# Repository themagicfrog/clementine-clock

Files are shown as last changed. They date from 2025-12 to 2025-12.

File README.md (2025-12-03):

# clementine clock

this is an orange/mandarin-themed clock to set timers & alarms for my room. I decided to make a clock because I usually don't have access
to my phone when I go to sleep at school, and I needed an easy way to know the time and to wake up at the right time. I chose a clementine
theme because I like oranges.

on the main PCB board, there is a 4-digit 7-segment LCD display (showing the time), a small button, and a speaker. there is also wires on the
main PCB board connecting a rotary encoder (adjusting the time) on the top of the orange, a 3 AA battery case, and a big button (snooze & stop) at the
"stem" of the clementine. the case is a 3D-printed cylindrical clementine case.

3dfront
3dback

pcb
schematic

## bill of materials
| Reference | Item | Description | Qty | Unit Price (USD) | Total (USD) | URL |
|---|---|---|-----|---|---|-----|
| U1 | Microcontroller | Seeed XIAO RP2040 | 1 | 4.68 | 4.68 | https://www.digikey.com/en/products/detail/seeed-technology-co-ltd/102010428/14672129 |
| J1_DISPLAY | LCD Display | Grove LCD Screen (104030003) | 1 | 6.50 | 6.50 | https://www.digikey.com/en/products/detail/seeed-technology-co-ltd/104030003/5488009 |
| U2 | Voltage Regulator  | MIC5219-3.3YM5 3.3V LDO | 1 | 1.19 | 1.19 | https://www.digikey.com/en/products/detail/microchip-technology/MIC5219-3-3YM5-TR/771750 |
| U3 | Audio Amplifier | PAM8302AAD | 1 | 0.48 | 0.48 | https://www.digikey.com/en/products/detail/diodes-incorporated/pam8302aadcr/4033280 |
| LS1 | Speaker | SC250708-1 8Ω Speaker | 1 | 2.96 | 2.96 | https://www.digikey.com/en/products/detail/db-unlimited/SC250708-1/9990569 |
| SW1 | Rotary Encoder | ACZ11BR4E-15FD1-20C | 1 | 3.22 | 3.22 | https://www.digikey.com/en/products/detail/same-sky-formerly-cui-devices/acz11br4e-15fd1-20c/1923364 |
| SW2 | Pushbutton (Big) | RP3502ARED | 1 | 2.29 | 2.29 | https://www.digikey.com/en/products/detail/e-switch/RP3502ARED/280448 |
| SW3 | Pushbutton (Small) | Y97HT21A2FAFP | 1 | 0.24 | 0.24 | https://www.digikey.com/en/products/detail/c-k/Y97HT21A2FAFP/3861375 |
| SW4 | Power Switch | PCM12SMTR slide SPST | 1 | 1.14 | 1.14 | https://www.digikey.com/en/products/detail/c-k/PCM12SMTR/1640112 |
| BT1_HOLDER | Battery Holder | Kitronik 2273 3×AAA w/ JST | 1 | 1.87 | 1.87 | https://www.digikey.com/en/products/detail/kitronik-ltd/2273/8635437 |
| BT1 | Battery Connector  | B2B-PH-K-S JST-PH 2-pin header | 1 | 0.10 | 0.10 | https://www.digikey.com/en/products/detail/jst-sales-america-inc/B2B-PH-K-S/926611 |
| J1 | LCD Header | PRPC004SAAN-RC 1×4 2.54mm | 1 | 0.34 | 0.34 | https://www.digikey.com/en/products/detail/adam-tech/RS1-04-G/9829303 |
| C1 | Capacitor | 10µF 10V X7R 0805 | 1 | 1.02 | 1.02 | https://www.digikey.com/en/products/detail/kemet/c0805x106j8rac7210/7423434 |
| C2 | Capacitor | 22µF 10V X5R 0805 | 1 | 0.15 | 0.15 | https://www.digikey.com/en/products/detail/yageo/CC0805MKX5R7BB226/5195308 |
| C3 | Capacitor | 0.22µF 50V X7R 0805 | 1 | 0.15 | 0.15 | https://www.digikey.com/en/products/detail/kemet/c0805c224k5ractu/754753 |
| C4 | Capacitor | 1µF 50V X7R 0805 | 1 | 0.81 | 0.81 | https://www.digikey.com/en/products/detail/kemet/C0805C105K5RACTU/3317615 |
| C5 | Capacitor | 10nF 250V 0805 | 1 | 0.08 | 0.08 | https://www.digikey.com/en/products/detail/kemet/C0805C103F5GECAUTO/8647276 |
| C6 | Capacitor | 4.7µF 50V X5R 0805 | 1 | 0.19 | 0.19 | https://www.digikey.com/en/products/detail/murata-electronics/grm21br61h475ke51l/4905540 |
| R1 | Resistor | 100kΩ 1% 0805 | 1 | 0.10 | 0.10 | https://www.digikey.com/en/products/detail/stackpole-electronics-inc/rmcf0805ft100k/1760712 |
| R2 | Resistor | 1kΩ 1% 0805 | 1 | 0.10 | 0.10 | https://www.digikey.com/en/products/detail/stackpole-electronics-inc/rmcf0805ft1k00/1760090 |
| D1 | LED | Red 0805 LED | 1 | 0.19 | 0.19 | https://www.digikey.com/en/products/detail/würth-elektronik/150080RS75000/4489918 |
| **TOTAL** | — | — | — | **Tax + Shipping = 3.12** | **44.26** | |

## made for [Blueprint](https://blueprint.hackclub.com/)
## find the Journal (devlogs) and project on Blueprint [here](https://blueprint.hackclub.com/projects/2563)

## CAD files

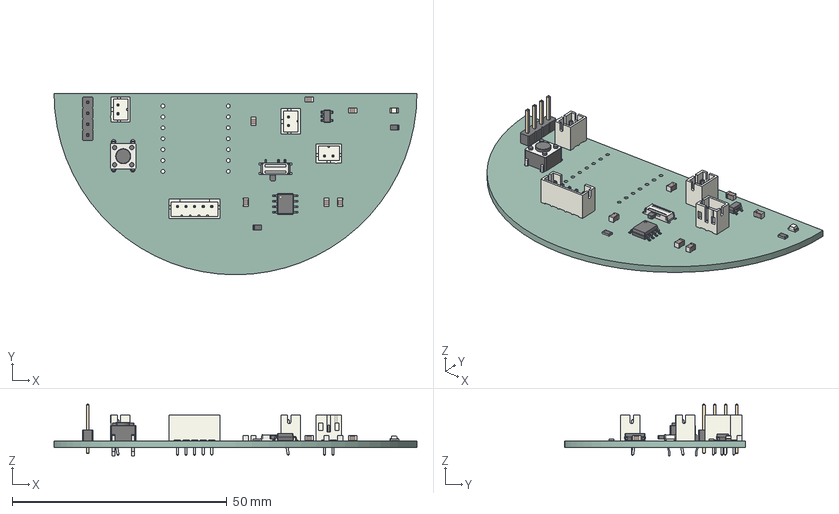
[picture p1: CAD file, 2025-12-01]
CAD/pcb.step
84.6 x 42.3 x 12.0 mm
PinHeader_1x04_P2.54mm_Vertical
C_0805_2012Metric x 6
SW_SPDT_PCM12
SOIC-8_3.9x4.9mm_P1.27mm
R_0805_2012Metric x 2
JST_PH_B2B-PH-K_1x02_P2.00mm_Vertical x 3
SOT-23-5
SW_PUSH_6mm
JST_PH_B5B-PH-K_1x05_P2.00mm_Vertical
LED_0805_2012Metric
clementine clock_PCB

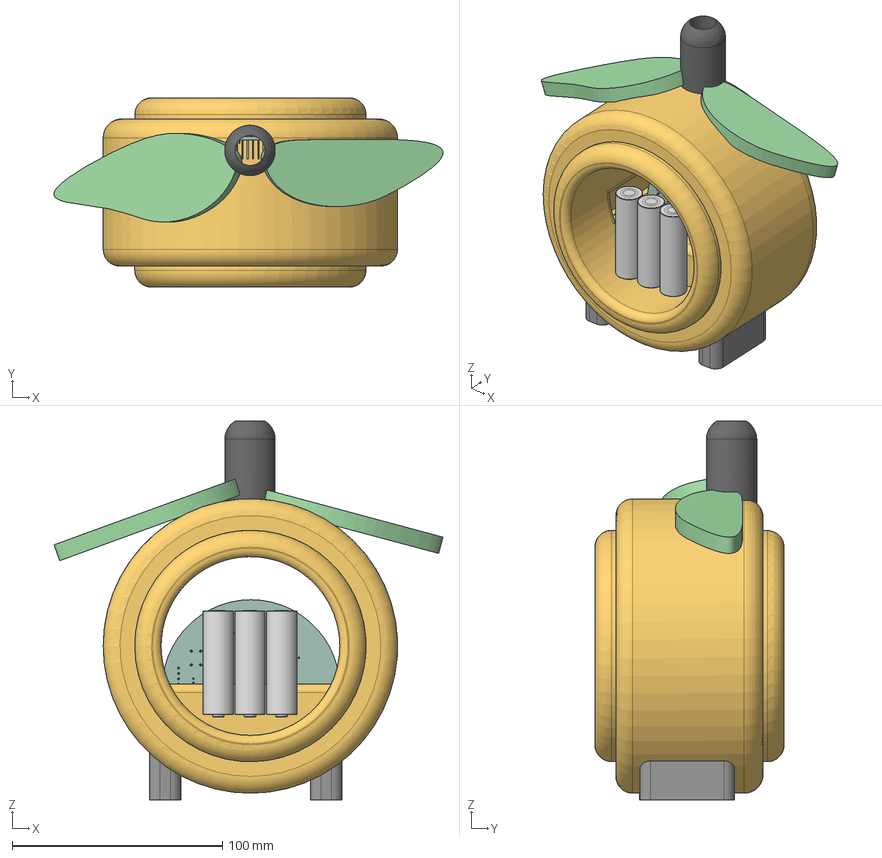
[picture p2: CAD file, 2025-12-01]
CAD/case.step
184.9 x 90.0 x 180.0 mm
PinHeader_1x04_P2.54mm_Vertical
C_0805_2012Metric x 6
SW_SPDT_PCM12
SOIC-8_3.9x4.9mm_P1.27mm
R_0805_2012Metric x 2
JST_PH_B2B-PH-K_1x02_P2.00mm_Vertical x 3
SOT-23-5
SW_PUSH_6mm
JST_PH_B5B-PH-K_1x05_P2.00mm_Vertical
LED_0805_2012Metric
clementine clock_PCB
AA Battery x 3

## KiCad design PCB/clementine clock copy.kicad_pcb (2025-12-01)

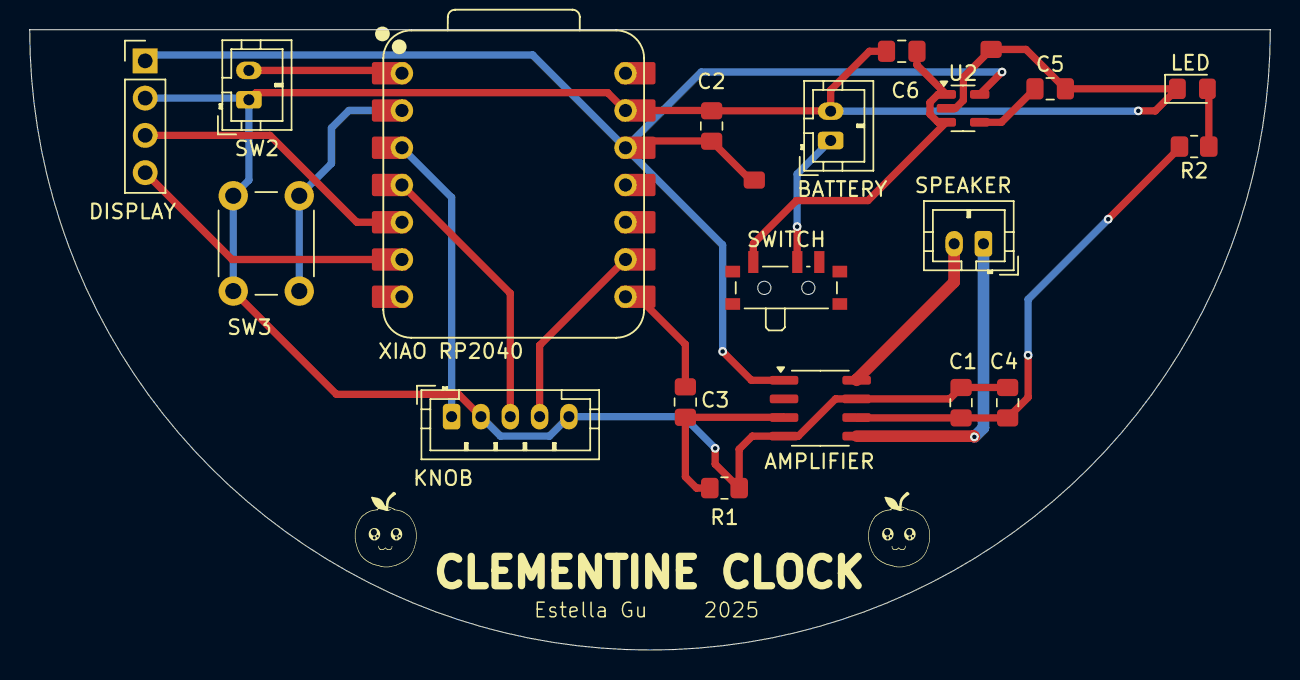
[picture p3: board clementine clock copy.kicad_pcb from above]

Board: 2 copper layers, 84.6 x 42.3 mm, 19 parts (0 on the bottom side), 17 nets.

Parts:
AMPLIFIER: PAM8302AAD; SOIC-8_3.9x4.9mm_P1.27mm
BATTERY: 4.5V (3xAA); JST_PH_B2B-PH-K_1x02_P2.00mm_Vertical
C1: 10 µF; C_0805_2012Metric_Pad1.18x1.45mm_HandSolder
C2: 22µF; C_0805_2012Metric_Pad1.18x1.45mm_HandSolder
C3: 0.22uF; C_0805_2012Metric_Pad1.18x1.45mm_HandSolder
C4: 1uF; C_0805_2012Metric_Pad1.18x1.45mm_HandSolder
C5: 10nF; C_0805_2012Metric_Pad1.18x1.45mm_HandSolder
C6: 4.7uF; C_0805_2012Metric_Pad1.18x1.45mm_HandSolder
DISPLAY: LCD _Screen; PinHeader_1x04_P2.54mm_Vertical
KNOB: RotaryEncoder_Switch; JST_PH_B5B-PH-K_1x05_P2.00mm_Vertical
LED: LED; LED_0805_2012Metric_Pad1.15x1.40mm_HandSolder
R1: 100k; R_0805_2012Metric_Pad1.20x1.40mm_HandSolder
R2: 1k; R_0805_2012Metric_Pad1.20x1.40mm_HandSolder
SPEAKER: Speaker; JST_PH_B2B-PH-K_1x02_P2.00mm_Vertical
SW2: SW_Push; JST_PH_B2B-PH-K_1x02_P2.00mm_Vertical
SW3: SW_Push; SW_PUSH_6mm
SW4: SW_SPST; SW_SPDT_PCM12
U2: MIC5219-3.3YM5; SOT-23-5
XIAO RP2040: XIAO-RP2040-DIP

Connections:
/3V3: AMPLIFIER.1 (~SD), AMPLIFIER.6 (VDD), C1.1, C2.1, C4.1, DISPLAY.1, R2.2, U2.5 (OUT), XIAO RP2040.12 (3V3)
/ENC_BTN: KNOB.4 (S1), XIAO RP2040.9 (GPIO2/SCK)
/GND: AMPLIFIER.4 (IN-), AMPLIFIER.7 (GND), BATTERY.2 (-), C1.2, C2.2, C4.2, C5.2, C6.1, DISPLAY.2, KNOB.2 (C), KNOB.5 (S2), LED.1 (K), R1.1, SW2.1, SW3.1, U2.2 (GND), XIAO RP2040.13 (GND)
/GPIO28: KNOB.1 (A), XIAO RP2040.3 (GPIO28/ADC2/A2)
/GPIO29: KNOB.3 (B), XIAO RP2040.4 (GPIO29/ADC3/A3)
/SCL: DISPLAY.4, XIAO RP2040.6 (GPIO7/SCL)
/SDA: DISPLAY.3, XIAO RP2040.5 (GPIO6/SDA)
unnamed: BATTERY.1 (+), SW4.2 (B)
unnamed: LED.2 (A), R2.1
unnamed: C6.2, SW4.1 (A), U2.1 (IN), U2.3 (EN)
unnamed: C3.1, XIAO RP2040.8 (GPIO1/RX)
unnamed: SW2.2, XIAO RP2040.1 (GPIO26/ADC0/A0)
unnamed: SW3.2, XIAO RP2040.2 (GPIO27/ADC1/A1)
unnamed: C5.1, U2.4 (BP)
unnamed: AMPLIFIER.3 (IN+), C3.2, R1.2
unnamed: AMPLIFIER.5 (OUT+), SPEAKER.1
unnamed: AMPLIFIER.8 (OUT-), SPEAKER.2

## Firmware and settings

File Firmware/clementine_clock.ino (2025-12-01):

#include <Wire.h>
#include <LiquidCrystal_I2C.h>
#include <RTClib.h>

#define PIN_BIG_BUTTON 26
#define PIN_SMALL_BUTTON 27
#define PIN_ENCODER_A 28
#define PIN_ENCODER_B 29
#define PIN_ENCODER_BTN 2
#define PIN_SPEAKER 1

LiquidCrystal_I2C lcd(0x27, 16, 2);

RTC_Millis rtc;

int currentHour = 12;
int currentMinute = 0;
int currentSecond = 0;
unsigned long lastMinuteUpdate = 0;
unsigned long lastSecondUpdate = 0;
unsigned long last5MinuteSound = 0;

volatile int encoderPosition = 0;
int lastEncoderPosition = 0;
int lastEncoderA = 0;
int lastEncoderB = 0;
bool encoderPressed = false;
bool lastEncoderPressed = false;
bool timeAdjustMode = false;
int adjustField = 0;
unsigned long encoderButtonPressTime = 0;

bool bigButtonPressed = false;
bool lastBigButtonPressed = false;

bool displayNeedsUpdate = true;

void setup() {
  Serial.begin(115200);
  delay(1000);
  Serial.println("Clementine Clock Starting...");

  Wire.begin();
  
  lcd.init();
  lcd.backlight();
  lcd.clear();
  lcd.setCursor(0, 0);
  lcd.print("Clementine");
  lcd.setCursor(0, 1);
  lcd.print("Clock");
  delay(2000);
  lcd.clear();

  rtc.begin(DateTime(F(__DATE__), F(__TIME__)));
  DateTime now = rtc.now();
  currentHour = now.hour();
  currentMinute = now.minute();
  currentSecond = now.second();

  pinMode(PIN_BIG_BUTTON, INPUT_PULLUP);
  pinMode(PIN_SMALL_BUTTON, INPUT_PULLUP);
  pinMode(PIN_ENCODER_A, INPUT_PULLUP);
  pinMode(PIN_ENCODER_B, INPUT_PULLUP);
  pinMode(PIN_ENCODER_BTN, INPUT_PULLUP);
  pinMode(PIN_SPEAKER, OUTPUT);

  lastEncoderA = digitalRead(PIN_ENCODER_A);
  lastEncoderB = digitalRead(PIN_ENCODER_B);

  updateDisplay();
  
  Serial.println("Clock initialized!");
}

void loop() {
  unsigned long currentMillis = millis();

  if (currentMillis - lastSecondUpdate >= 1000) {
    lastSecondUpdate = currentMillis;
    currentSecond++;
    if (currentSecond >= 60) {
      currentSecond = 0;
      currentMinute++;
      if (currentMinute >= 60) {
        currentMinute = 0;
        currentHour++;
        if (currentHour >= 24) {
          currentHour = 0;
        }
      }
    }
  }

  if (currentMillis - lastMinuteUpdate >= 60000) {
    lastMinuteUpdate = currentMillis;
    displayNeedsUpdate = true;
    
    if (currentMinute % 5 == 0 && currentSecond == 0) {
      if (currentMillis - last5MinuteSound >= 60000) {
        last5MinuteSound = currentMillis;
        playSound();
      }
    }
  }

  readRotaryEncoder();
  
  readButtons();

  if (timeAdjustMode) {
    handleTimeAdjustment();
  }

  if (displayNeedsUpdate) {
    updateDisplay();
    displayNeedsUpdate = false;
  }

  delay(10);
}

void readRotaryEncoder() {
    encoderPressed = !digitalRead(PIN_ENCODER_BTN);
  
  if (encoderPressed && !lastEncoderPressed) {
    timeAdjustMode = true;
    adjustField = 0;
    encoderButtonPressTime = millis();
    encoderPosition = 0;
    lastEncoderPosition = 0;
    Serial.println("Entering time adjustment mode - adjust hour");
    displayNeedsUpdate = true;
  }
  
  if (!encoderPressed && lastEncoderPressed) {
    if (timeAdjustMode) {
      if (adjustField == 0) {
        adjustField = 1;
        encoderPosition = 0;
        lastEncoderPosition = 0;
        Serial.println("Switching to minute adjustment");
        displayNeedsUpdate = true;
      } else {
        timeAdjustMode = false;
        Serial.println("Exiting time adjustment mode");
        displayNeedsUpdate = true;
      }
    }
  }
  
  lastEncoderPressed = encoderPressed;

  if (encoderPressed && timeAdjustMode) {
    int encoderA = digitalRead(PIN_ENCODER_A);
    int encoderB = digitalRead(PIN_ENCODER_B);
    
    if (encoderA != lastEncoderA || encoderB != lastEncoderB) {
      if (lastEncoderA == LOW && encoderA == HIGH) {
        if (encoderB == LOW) {
          encoderPosition++;
        } else {
          encoderPosition--;
        }
      } else if (lastEncoderB == LOW && encoderB == HIGH) {
        if (encoderA == LOW) {
          encoderPosition--;
        } else {
          encoderPosition++;
        }
      }
      
      lastEncoderA = encoderA;
      lastEncoderB = encoderB;
    }
    
    if (encoderPosition != lastEncoderPosition) {
      int change = encoderPosition - lastEncoderPosition;
      
      if (adjustField == 0) {
        currentHour += change;
        if (currentHour < 0) currentHour = 23;
        if (currentHour >= 24) currentHour = 0;
        Serial.print("Hour adjusted to: ");
        Serial.println(currentHour);
      } else {
        currentMinute += change;
        if (currentMinute < 0) {
          currentMinute = 59;
          currentHour--;
          if (currentHour < 0) currentHour = 23;
        }
        if (currentMinute >= 60) {
          currentMinute = 0;
          currentHour++;
          if (currentHour >= 24) currentHour = 0;
        }
        Serial.print("Minute adjusted to: ");
        Serial.println(currentMinute);
      }
      
      lastEncoderPosition = encoderPosition;
      displayNeedsUpdate = true;
      currentSecond = 0;
    }
  } else if (!encoderPressed) {
    lastEncoderA = digitalRead(PIN_ENCODER_A);
    lastEncoderB = digitalRead(PIN_ENCODER_B);
    encoderPosition = 0;
    lastEncoderPosition = 0;
  }
}

void readButtons() {
  bigButtonPressed = !digitalRead(PIN_BIG_BUTTON);
  
  if (bigButtonPressed && !lastBigButtonPressed) {
    Serial.println("Big button pressed");
  }
  
  lastBigButtonPressed = bigButtonPressed;
}

void handleTimeAdjustment() {
}

void updateDisplay() {
  lcd.clear();
  
  if (timeAdjustMode) {
    lcd.setCursor(0, 0);
    if (adjustField == 0) {
      lcd.print("Adjust Hour:");
    } else {
      lcd.print("Adjust Minute:");
    }
    lcd.setCursor(0, 1);
  } else {
    lcd.setCursor(0, 0);
  }
  
  char timeStr[6];
  sprintf(timeStr, "%02d:%02d", currentHour, currentMinute);
  lcd.print(timeStr);
  
  if (timeAdjustMode) {
    lcd.setCursor(5, 1);
    if (adjustField == 0) {
      lcd.print("^");
    } else {
      lcd.setCursor(3, 1);
      lcd.print("^");
    }
  }
}

void playSound() {
  
  unsigned long toneStart = millis();
  unsigned long toneDuration = 200;
  
  while (millis() - toneStart < toneDuration) {
    digitalWrite(PIN_SPEAKER, HIGH);
    delayMicroseconds(500);
    digitalWrite(PIN_SPEAKER, LOW);
    delayMicroseconds(500);
  }
  
  delay(50);
  
  toneStart = millis();
  while (millis() - toneStart < toneDuration) {
    digitalWrite(PIN_SPEAKER, HIGH);
    delayMicroseconds(416);
    digitalWrite(PIN_SPEAKER, LOW);
    delayMicroseconds(416);
  }
  
  digitalWrite(PIN_SPEAKER, LOW);
  
  Serial.println("5-minute sound played");
}

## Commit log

2025-12-01 add bom
    [BOM.csv]
2025-12-02 add gerbers
